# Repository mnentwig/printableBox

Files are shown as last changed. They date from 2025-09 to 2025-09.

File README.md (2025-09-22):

# printableBox
Parametric openSCAD 3d-printable box generator e.g. electronics case with rounded edges, two shells, an overlapping lid.

### Example
Sample box with screws, cutouts and ribs (all optional features)
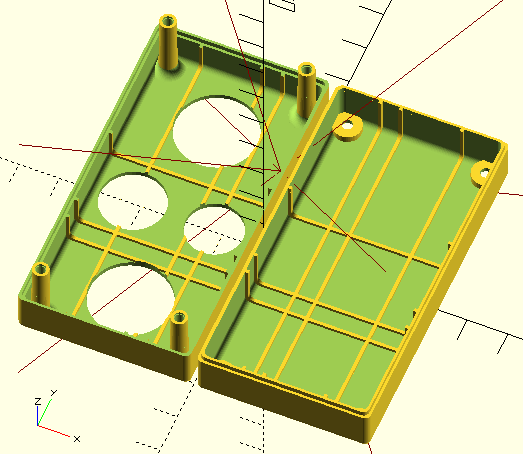
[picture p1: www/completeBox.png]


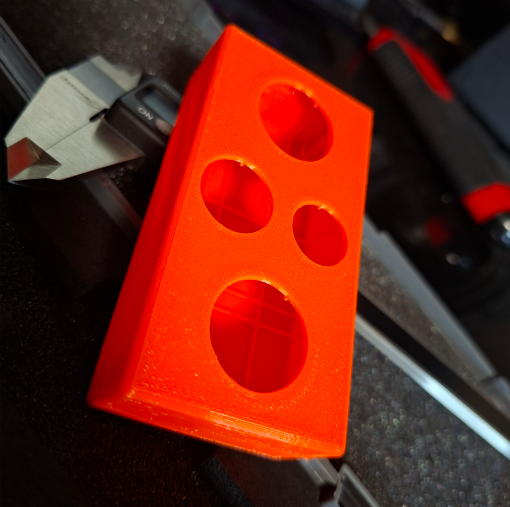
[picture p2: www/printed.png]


To run, open "main.scad" in openSCAD and preview or render.

### Features
- Box geometry is freely adjustable in main.scad. 

- Any number of screws can be placed freely (also merged into a rounded edge or corner)

- Cutouts can be placed on top and bottom side, e.g. for switches, ventilation or just a cool swiss-cheese effect (=to speed up test prints)

- Internal ribs can be placed individually, e.g. where box contents allow

### Clipping
Quite a bit more complex than originally envisioned - it's just a box, right? Right...

But, hopefully correct: screw boss pads don't stick out, screw heads merge into the wall, cutouts remove ribs underneath.

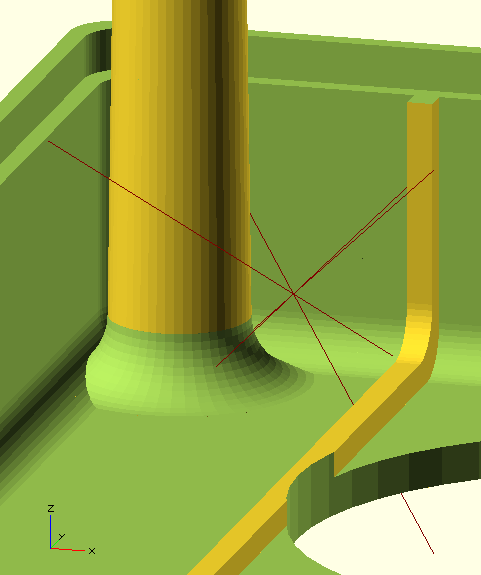
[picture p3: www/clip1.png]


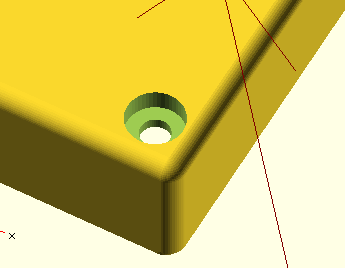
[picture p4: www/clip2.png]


### Code / implementation notes
Design information is passed in as a hash table. 

"ScrewBoss.scad" shows a reusable module with test cases that gets its input from a shared data structure, identified by a prefix (e.g. if a design needs to use screw bosses of different size)

### Test prints
No real issues in half a dozen test prints at different design stages (Prusa Core One, Structural 0.15 mm in PETG).

Lessons learned: 
- Use the shortest practical thread length. If longer screws have to be used, the "shank" setting provides a non-threaded hole for most of the screw length (which creates less stress on the screw boss and is more convenient to assemble).
- Shells may not be joined by force, as the final corner may splinter. Slightly breaking each shell's corners (outside-/inside) with a carpet knife avoids this problem. 
- Assembly technique tends to improve with practice :-)
- Strategically placed ribs will significantly improve stiffness.

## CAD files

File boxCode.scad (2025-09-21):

use <screwBoss.scad>
function get_param(params, key) =
    let (tmp = [for (p = params) if (p[0]==key) p[1]])
        len(tmp) == 1 ? tmp[0] : assert(0, str("parameter '", key, "' not found"));

module bodyBoxPrimitive(innerWidth, innerLength, innerHeight, outerRadius){
	minkowski(){
		cube([innerWidth-2*outerRadius, innerLength-2*outerRadius, innerHeight-2*outerRadius], center=true); 
		sphere(r=outerRadius);
	}
};

// internal parameters depend on user input, calculated here
function boxGeom_dependentFields(geom) = 
    let(
        // === recall independent parameters ===
        screwBossPrefix = get_param(geom, "screwBossPrefix"), 
        innerHeight=get_param(geom, "innerHeight"),
        wallThickness=get_param(geom, "wallThickness"))
        // === set dependents ===
            concat(geom, 
                // the "screwBoss" length includes the thickness of the wall on the screw hole side
                // but not the wall where the screw boss attaches on the inside.
                [[str(screwBossPrefix, ".bossLength"), 
                innerHeight + wallThickness]]);

module cutoutsXYR(cutoutsXYR, cutoutZ, cutoutThickness){
    for (cutoutXYR = cutoutsXYR){
        assert(len(cutoutXYR) == 3, "expecting three-field element for cutoutsTopXYR");
        let(cutoutX = cutoutXYR[0], cutoutY = cutoutXYR[1], cutoutR = cutoutXYR[2]){
            translate([cutoutX, cutoutY, cutoutZ])
                        linear_extrude(height = cutoutThickness)
                            circle(r=cutoutR);
        }; // let
    }; // for cutout    
} // module

module boxTop(geom_){
    geom = boxGeom_dependentFields(geom_);
    screwXY=get_param(geom, "screwXY"); 
    innerHeight=get_param(geom, "innerHeight");
    wallThickness=get_param(geom, "wallThickness"); 
    screwBossPrefix = get_param(geom, "screwBossPrefix");
    screwBossZ = -innerHeight/2 - wallThickness;
    eps=get_param(geom, "eps"); 

    cutoutsXYR = get_param(geom, "cutoutsTopXYR");
    cutoutEps = 0.1;
    cutoutZ = -innerHeight/2-wallThickness-cutoutEps;
    cutoutThickness = wallThickness+2*cutoutEps;

    difference(){
        // === ADD ===
        intersection(){
            union(){
                // shell
                caseTop(geom);
                // screw bosses 
                for (screw = screwXY){
                    let(screwX = screw[0], screwY = screw[1]){
                        translate([screwX, screwY, -screwBossZ])
                            rotate([0, 180, 0]) // note: screw "top" goes into "bottom" case shell
                                screwBossBottomAdd(geom, screwBossPrefix);
                    } // let
                }; // for screw
            }; // union (+)
            // === clip screw butts to outer shell ===
            caseOuterShell(geom);
        }; // intersection 
        // === SUBTRACT ===
        union(){
            // cut screw bosses that extend into top-/bottom connection area
            caseBottom(geom);
            // cut screw holes
            for (screw = screwXY){
                let(screwX = screw[0], screwY = screw[1]){
                    translate([screwX, screwY, -screwBossZ])
                        rotate([0, 180, 0])
                            screwBossSub(geom, screwBossPrefix);            
                }; // let
            }; // for screw
            cutoutsXYR(cutoutsXYR, cutoutZ, cutoutThickness);
        } // union (-)    
    }; // difference       
} // module

module boxBottom(geom_){
    geom = boxGeom_dependentFields(geom_);
    screwXY=get_param(geom, "screwXY"); 
    innerHeight=get_param(geom, "innerHeight");
    wallThickness=get_param(geom, "wallThickness"); 
    screwBossPrefix = get_param(geom, "screwBossPrefix");
    screwBossZ = -innerHeight/2 - wallThickness;

    cutoutsXYR = get_param(geom, "cutoutsBottomXYR");
    cutoutEps = 0.1;
    cutoutZ = innerHeight/2-cutoutEps;
    cutoutThickness = wallThickness+2*cutoutEps;

    difference(){
        // === ADD ===
        intersection(){
            union(){
                // shell
                caseBottom(geom);
                // screw bosses 
                for (screw = screwXY){
                    let(screwX = screw[0], screwY = screw[1]){
                        translate([screwX, screwY, -screwBossZ])
                            rotate([0, 180, 0]) // note: screw "top" goes into "bottom" case shell
                                screwBossTopAdd(geom, screwBossPrefix);
                    } // let
                }; // for screw
            }; // union (+)
            // === clip screw head recesses to outer shell ===
            caseOuterShell(geom);
        };
        // === SUBTRACT ===
        union(){
            // cut screw bosses that extend into top-/bottom connection area
            caseTop(geom);
            // cut screw holes
            for (screw = screwXY){
                let(screwX = screw[0], screwY = screw[1]){
                    translate([screwX, screwY, -screwBossZ])
                        rotate([0, 180, 0])
                            screwBossSub(geom, screwBossPrefix);            
                }; // let
            } // for screw
            cutoutsXYR(cutoutsXYR, cutoutZ, cutoutThickness);
        } // union (-)    
    }; // difference       
} // module

module caseBottom(geom){
    intersection(){
        caseTopBottom(geom);
        caseKeepBottom(geom);    
    }
}

module caseTop(geom){
    difference(){
        caseTopBottom(geom);
        caseKeepBottom(geom);    
    }
}

module caseKeepBottom(geom){
    myInfinity=get_param(geom, "infinity"); 
    eps=get_param(geom, "eps"); 
	outerRadius=get_param(geom, "outerRadius"); 
    rimThickness = 0.5*get_param(geom, "wallThickness"); 
    rimHeight = 1.1*get_param(geom, "wallThickness"); 
    innerWidth=get_param(geom, "innerWidth"); 
    innerLength=get_param(geom, "innerLength"); 

    union(){
        // shell to keep is positive z
        translate([0,0,myInfinity/2])
            cube([myInfinity+eps, myInfinity+eps, myInfinity+eps], center=true);
        // add a half-thickness rim to align the shells
        translate([0, 0, -rimHeight])
            linear_extrude(height=rimHeight+eps)
                minkowski(){
                    circle(r=outerRadius); 
                    square([
                        innerWidth-2*outerRadius+2*rimThickness, 
                        innerLength-2*outerRadius+2*rimThickness], 
                        center=true);                
                } // minkowski
    } // union
} // module

module caseOuterShell(geom){
    innerWidth=get_param(geom, "innerWidth"); 
    innerLength=get_param(geom, "innerLength"); 
    innerHeight=get_param(geom, "innerHeight");
    outerRadius=get_param(geom, "outerRadius"); 
    wallThickness=get_param(geom, "wallThickness"); 

    bodyBoxPrimitive(innerWidth+2*wallThickness, innerLength+2*wallThickness, innerHeight+2*wallThickness, outerRadius);
} // module

module caseInnerShell(geom){
    innerWidth=get_param(geom, "innerWidth"); 
    innerLength=get_param(geom, "innerLength"); 
    innerHeight=get_param(geom, "innerHeight");
    outerRadius=get_param(geom, "outerRadius"); 

    bodyBoxPrimitive(innerWidth, innerLength, innerHeight, outerRadius);
}

module caseTopBottom(geom){
    difference(){
        caseOuterShell(geom);
        caseInnerShell(geom);
	}
};

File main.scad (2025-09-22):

// ======================================
// = 3D printable DIY box               =
// = 2025 Markus Nentwig                =
// = This file is in the public domain. =
// ======================================
// open with openSCAD, "render" (F6), "export"

use<src/boxCode.scad>
use<src/screwBoss.scad>

// This file: user-defineable parameters and placement of the two shells for export

// === Parameters (mm) ===

// case geometry defaults. Those can be set from the command line
// Example invocation (Windows CMD prompt):
// "C:\Program Files (x86)\OpenSCAD\openscad.exe" -D wi=100 -D hi=25 -D li=200 -o myExport.stl main.scad

wi = is_undef(wi) ? 40 : wi;
li = is_undef(li) ? 80 : li;
hi = is_undef(hi) ? 20 : hi;
wt = is_undef(wt) ? 1.2 : wt;

// screw placement defaults (see below, any number of screws can be positioned at individual XY coordinates)
screwX = wi/2-3;
screwY = li/2-3;

// Geometry description, all units mm
geom=[
    // === box parameters ===
    ["innerWidth", wi],     // inside width at center (each shell fits a narrow object of this width)
    ["innerLength", li],    // inside length at center (each shell fits a narrow object of this length)
    ["innerHeight", hi],    // inside height at center (assembled shells fit a narrow object of this height)
    ["outerRadius", 1.5],     // radius of corners << min(width, height). Set zero-ish value for square box
    ["wallThickness", wt],   // width of the walls on every face 
    ["screwBossPrefix", "myScrewA"], // (see below: allows reuse of module with independent parameter sets)

    // === screw boss parameters ===    
    // threaded hole. Mx minus some margin. E.g. -10% (that is, 2.7mm for M3), tune for printer.
    // Below is for M2.5
    ["myScrewA.threadDiam", 2.2],   // screw hole diameter (threaded part)
    // non-threaded hole. Mx plus some margin. E.g. +10% (that is, 3.3mm for M3), tune for printer.
    ["myScrewA.shankDiam", 2.6],   // screw hole diameter (non-threaded part)
    ["myScrewA.shankLength", 1.5],   // bolt length between head and threaded end. Depends on actual screw. Needs at least headWallThickness for non-threaded hole on the screw head side plus ~0.5mm or more for easier insertion
    ["myScrewA.headHeight", 2],   // screw head height
    ["myScrewA.headDiam", 5],   // screw head diameter
    ["myScrewA.headWallThickness", 1.0], // thickness of screw recess (load bearing!)
    ["myScrewA.standoffWallThicknessLo", 0.9], // thickness of standoff where the screw enters (minimum torque)
    ["myScrewA.standoffWallThicknessHi", 1.1], // thickness of standoff at boss end (maximum torque)
    ["myScrewA.bossPadDiam", 8.5], // standoff extension to distribute force (prelim)
    
    // === screws ===
    // (arbitrary number, user placed because application-dependent. 
    // Use ["screwXY", []] for no screws
    ["screwXY", [[screwX, screwY], [-screwX, screwY], [screwX, -screwY], [-screwX, -screwY]]],
    
    ["cutoutsTopXYR", [[0, -25, 10], [0, 25, 10], [-10, 0, 8], [10, 0, 7]]],
    ["cutoutsBottomXYR", []], //[[0, -25, 13], [0, 25, 12], [6, 0, 10], [-12, 8, 6], [-12, -7, 5]]],

    // === ribs ===
    ["ribsInnerThickness", 0.8],
    ["ribsInnerX", [-10, 5, 10]],
    ["ribsInnerY", [-15, -10, 10]],
    
    // === system-wide parameters === 
    ["infinity", 345],      // "large number" use reasonable value when working with preview
    ["eps", 0.01],           // "small number" for overlapping solids
    ];

if (0){
    // use this part for step-by-step debugging
    echo("Debug mode: Lining up steps on x axis");
    $fn=10;
    delta = 1.5*wi;
    translate([0*delta, 0, 0])caseTopBottom(geom);
    translate([1*delta, 0, 0])caseTop(geom);
    translate([2*delta, 0, 0])caseBottom(geom);
    translate([3*delta, 0, 0])boxTop(geom);
    translate([4*delta, 0, 0])boxBottom(geom);
} else {
    echo("Production mode, rendering"); 
    $fn=50;
    lowerShellThickness = hi/2+wt;
    translate([-0.55*wi, 0, lowerShellThickness])
        boxTop(geom);
    translate([0.55*wi, 0, lowerShellThickness])rotate([0, 180, 0]) 
        boxBottom(geom);
}

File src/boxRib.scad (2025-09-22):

boxRibTest();
module boxRibTest(){
    boxRib(50, 40, 2, 5);
}

module roundedRectangle(w, h, r){
    minkowski(){
        square([w-2*r, h-2*r], center=true);
        circle(r);
    }
}

module boxRib(w, h, t, r){
    translate([0, 0, -t/2])
        linear_extrude(height = t)
            difference(){
                roundedRectangle(w+2*t, h+2*t, r);
                roundedRectangle(w, h, r);
            }        
}
    

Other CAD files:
src/boxCode.scad
src/screwBoss.scad

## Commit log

2025-09-20 to git
    [boxCode.scad, main.scad]
2025-09-20 added holes
    [boxCode.scad, main.scad]
2025-09-20 smaller radius in example box
    [main.scad]
2025-09-21 major refactoring, improved screw boss
    [boxCode.scad, main.scad, screwBoss.scad]
2025-09-21 round cutouts
    [boxCode.scad, main.scad]
2025-09-21 fixed screw boss length error
    [boxCode.scad, screwBoss.scad]
2025-09-21 screw boss pads (prelim)
    [boxCode.scad, main.scad, screwBoss.scad]
2025-09-21 spherical screw boss pads
    [boxCode.scad, main.scad, screwBoss.scad]
2025-09-22 added ribs, reordered files
    [boxCode.scad, boxRib.scad, main.scad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]
